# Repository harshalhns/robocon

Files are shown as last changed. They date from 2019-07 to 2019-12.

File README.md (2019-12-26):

# robocon
<pre>This project contains hardware details and AVR code for manual robot that was used in Robocon 2019. 
It is based on swerve drive. Four Atmega32 controllers are responsible for turning of each wheel to a precise target angle. 
These 4 slave controllers receive commands from master Atmega2560 via SPI. 
The robot is operated using Android mobile phone. It connects to phone through ESP8266 wifi module.</pre>

Movement of MR1: https://drive.google.com/file/d/1RZcdZKO_QcPA8YeLSfsehZz7-IaqJbko/view?ts=5e0452a6<br/>
Passing mech: https://drive.google.com/file/d/1aKHcwnHMSf9a8_czkzGeTRfraIhykFKB/view?ts=5e0452bf<br/>
Throwing mech: https://drive.google.com/file/d/1u2j3kQulj4zu3Mqgoj5k-V91Kau0ibW5/view?ts=5e045611<br/>
Movement of MR2: https://drive.google.com/file/d/1vg7AJLM3L7O4et1_eYZHAmFJQMHMDMgw/view?ts=5e045298<br/>

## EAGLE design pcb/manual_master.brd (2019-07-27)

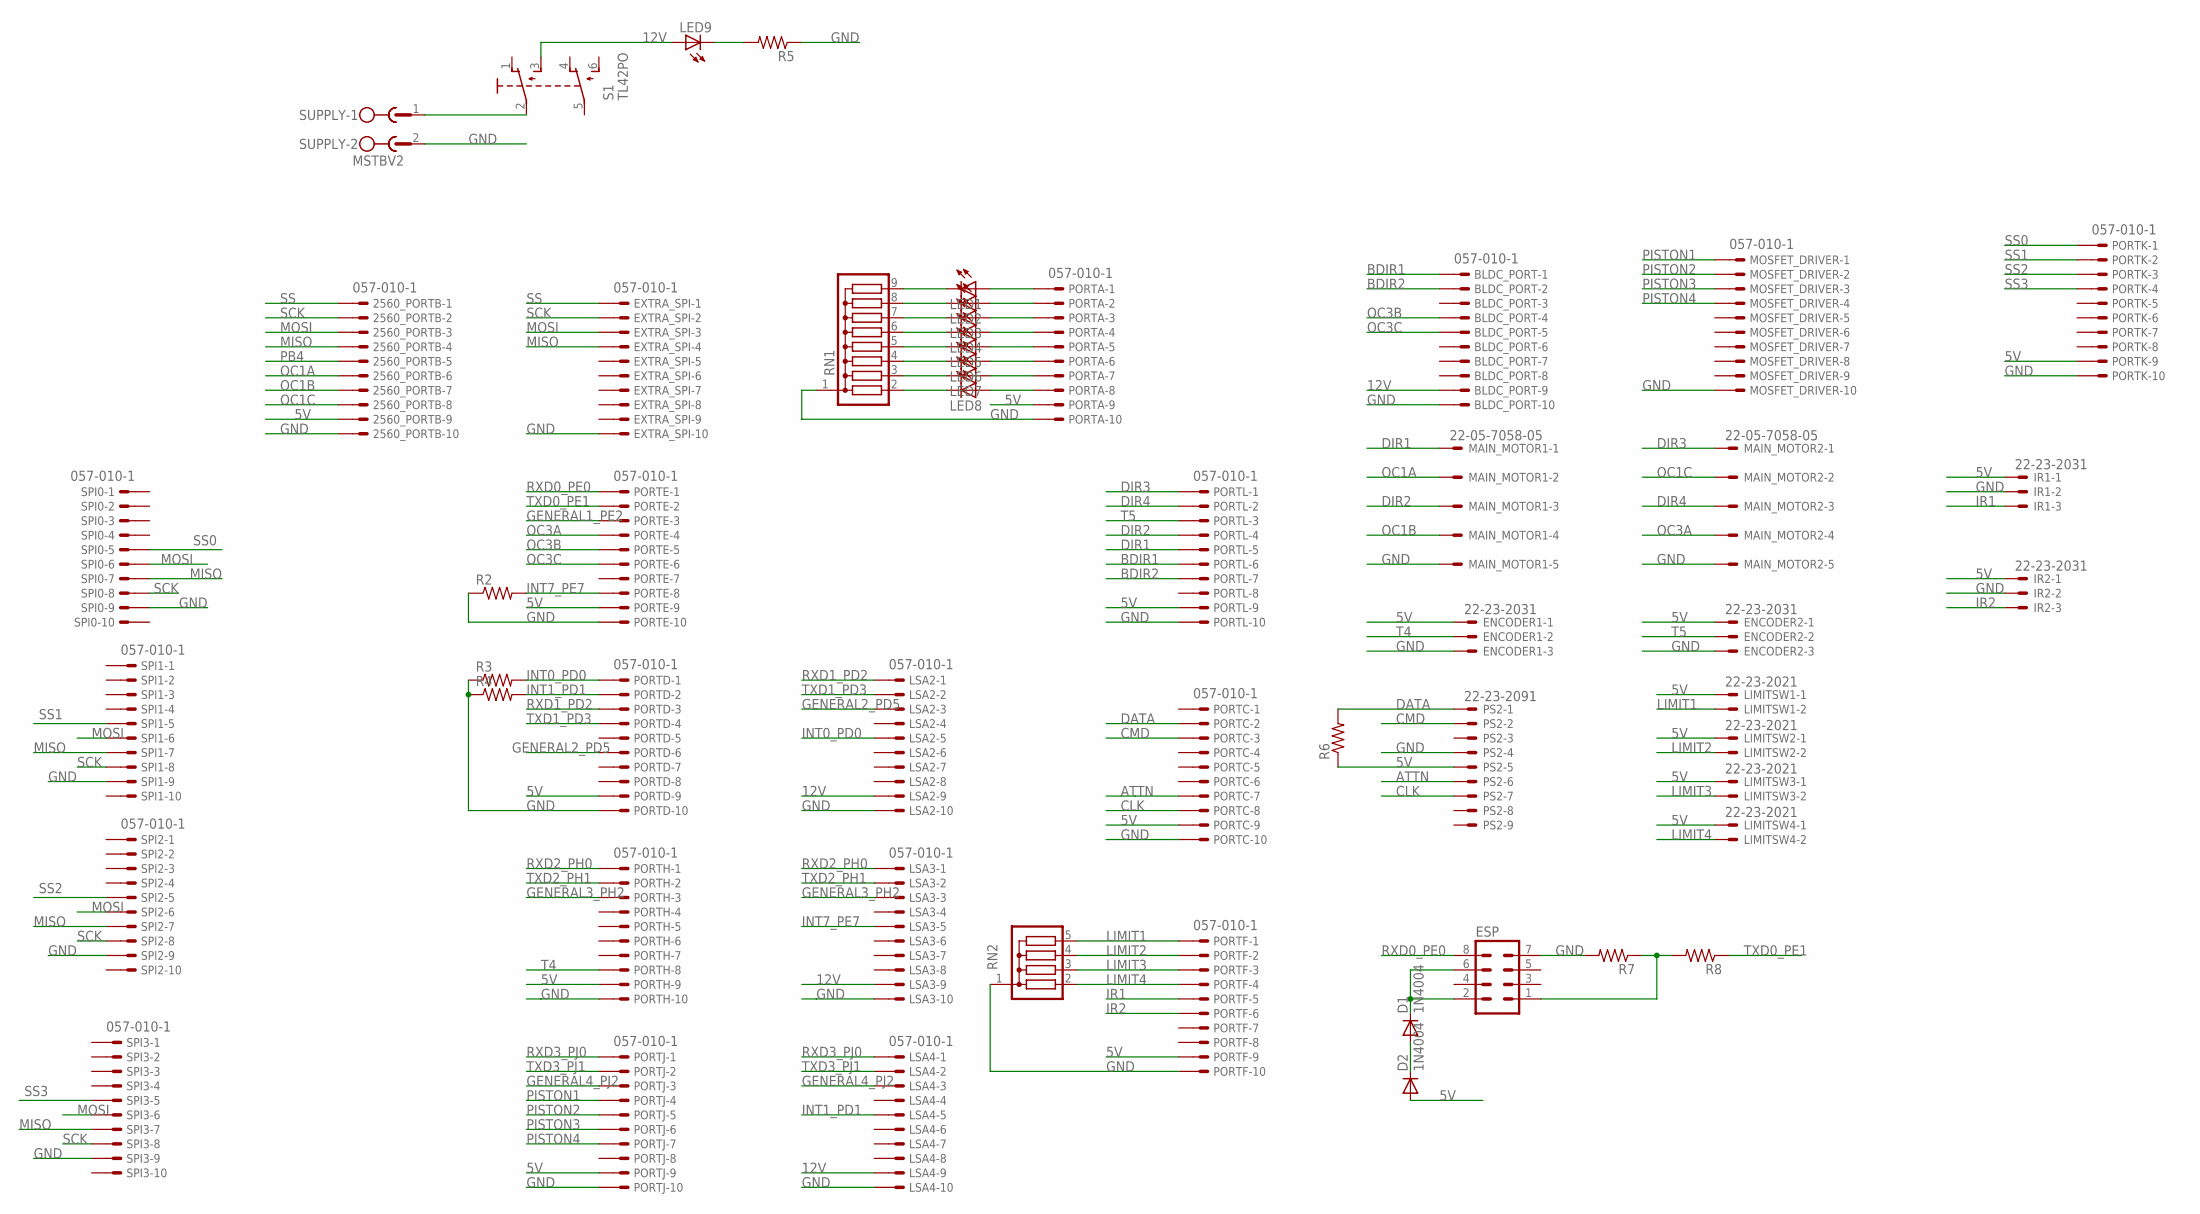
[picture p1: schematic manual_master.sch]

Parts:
2560_PORTB: 057-010-1
BLDC_PORT: 057-010-1
D1, D2: 1N4004; DO41-10
ENCODER1, ENCODER2: 22-23-2031
ESP: MA04-2
EXTRA_SPI: 057-010-1
IR1, IR2: 22-23-2031
LED1, LED2, LED3, LED4, LED5, LED6, LED7, LED8: LED3MM
LED9: LED5MM
LIMITSW1, LIMITSW2, LIMITSW3, LIMITSW4: 22-23-2021
LSA2, LSA3, LSA4: 057-010-1
MAIN_MOTOR1, MAIN_MOTOR2: 22-05-7058-05; 7395-05
MOSFET_DRIVER: 057-010-1
PORTA: 057-010-1
PORTC: 057-010-1
PORTD: 057-010-1
PORTE: 057-010-1
PORTF: 057-010-1
PORTH: 057-010-1
PORTJ: 057-010-1
PORTK: 057-010-1
PORTL: 057-010-1
PS2: 22-23-2091
R2, R3, R4, R5, R6, R7, R8: R-US_0207/10; 0207/10
RN1: G08R; SIL9
RN2: G04R; SIL5
S1: TL42PO; TL4XPO
SPI0, SPI1, SPI2, SPI3: 057-010-1
SUPPLY: MSTBV2

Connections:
5V: 2560_PORTB.9, D2.A, ENCODER1.1, ENCODER2.1, IR1.1, IR2.1, LIMITSW1.1, LIMITSW2.1, LIMITSW3.1, LIMITSW4.1, PORTA.9, PORTC.9, PORTD.9, PORTE.9, PORTF.9, PORTH.9, PORTJ.9, PORTK.9, PORTL.9, PS2.5, R6.1
12V: BLDC_PORT.9, LED9.A, LSA2.9, LSA3.9, LSA4.9, S1.3 (S)
ATTN: PORTC.7, PS2.6
BDIR1: BLDC_PORT.1, PORTL.6
BDIR2: BLDC_PORT.2, PORTL.7
CLK: PORTC.8, PS2.7
CMD: PORTC.3, PS2.2
DATA: PORTC.2, PS2.1, R6.2
DIR1: MAIN_MOTOR1.1, PORTL.5
DIR2: MAIN_MOTOR1.3, PORTL.4
DIR3: MAIN_MOTOR2.1, PORTL.1
DIR4: MAIN_MOTOR2.3, PORTL.2
GENERAL1_PE2: PORTE.3
GENERAL2_PD5: LSA2.3, PORTD.6
GENERAL3_PH2: LSA3.3, PORTH.3
GENERAL4_PJ2: LSA4.3, PORTJ.3
GND: 2560_PORTB.10, BLDC_PORT.10, ENCODER1.3, ENCODER2.3, ESP.7, EXTRA_SPI.10, IR1.2, IR2.2, LSA2.10, LSA3.10, LSA4.10, MAIN_MOTOR1.5, MAIN_MOTOR2.5, MOSFET_DRIVER.10, PORTA.10, PORTC.10, PORTD.10, PORTE.10, PORTF.10, PORTH.10, PORTJ.10, PORTK.10, PORTL.10, PS2.4, R2.1, R3.1, R4.1, R5.1, R7.2, RN1.1, RN2.1, SPI0.9, SPI1.9, SPI2.9, SPI3.9, SUPPLY.2
INT0_PD0: LSA2.5, PORTD.1, R3.2
INT1_PD1: LSA4.5, PORTD.2, R4.2
INT7_PE7: LSA3.5, PORTE.8, R2.2
IR1: IR1.3, PORTF.5
IR2: IR2.3, PORTF.6
LIMIT1: LIMITSW1.2, PORTF.1, RN2.5
LIMIT2: LIMITSW2.2, PORTF.2, RN2.4
LIMIT3: LIMITSW3.2, PORTF.3, RN2.3
LIMIT4: LIMITSW4.2, PORTF.4, RN2.2
MISO: 2560_PORTB.4, EXTRA_SPI.4, SPI0.7, SPI1.7, SPI2.7, SPI3.7
MOSI: 2560_PORTB.3, EXTRA_SPI.3, SPI0.6, SPI1.6, SPI2.6, SPI3.6
unnamed: D1.A, D2.C
unnamed: D1.C, ESP.2, ESP.6
unnamed: S1.2, SUPPLY.1
unnamed: LED9.K (C), R5.2
unnamed: LED1.A, PORTA.1
unnamed: LED2.A, PORTA.2
unnamed: LED3.A, PORTA.3
unnamed: LED4.A, PORTA.4
unnamed: LED5.A, PORTA.5
unnamed: LED6.A, PORTA.6
unnamed: LED7.A, PORTA.7
unnamed: LED8.A, PORTA.8
unnamed: LED1.K (C), RN1.9
unnamed: LED2.K (C), RN1.8
unnamed: ESP.1, R7.1, R8.2
unnamed: LED3.K (C), RN1.7
unnamed: LED4.K (C), RN1.6
unnamed: LED5.K (C), RN1.5
unnamed: LED6.K (C), RN1.4
unnamed: LED7.K (C), RN1.3
unnamed: LED8.K (C), RN1.2
OC1A: 2560_PORTB.6, MAIN_MOTOR1.2
OC1B: 2560_PORTB.7, MAIN_MOTOR1.4
OC1C: 2560_PORTB.8, MAIN_MOTOR2.2
OC3A: MAIN_MOTOR2.4, PORTE.4
OC3B: BLDC_PORT.4, PORTE.5
OC3C: BLDC_PORT.5, PORTE.6
PB4: 2560_PORTB.5
PISTON1: MOSFET_DRIVER.1, PORTJ.4
PISTON2: MOSFET_DRIVER.2, PORTJ.5
PISTON3: MOSFET_DRIVER.3, PORTJ.6
PISTON4: MOSFET_DRIVER.4, PORTJ.7
RXD0_PE0: ESP.8, PORTE.1
RXD1_PD2: LSA2.1, PORTD.3
RXD2_PH0: LSA3.1, PORTH.1
RXD3_PJ0: LSA4.1, PORTJ.1
SCK: 2560_PORTB.2, EXTRA_SPI.2, SPI0.8, SPI1.8, SPI2.8, SPI3.8
SS: 2560_PORTB.1, EXTRA_SPI.1
SS0: PORTK.1, SPI0.5
SS1: PORTK.2, SPI1.5
SS2: PORTK.3, SPI2.5
SS3: PORTK.4, SPI3.5
T4: ENCODER1.2, PORTH.8
T5: ENCODER2.2, PORTL.3
TXD0_PE1: PORTE.2, R8.1
TXD1_PD3: LSA2.2, PORTD.4
TXD2_PH1: LSA3.2, PORTH.2
TXD3_PJ1: LSA4.2, PORTJ.2

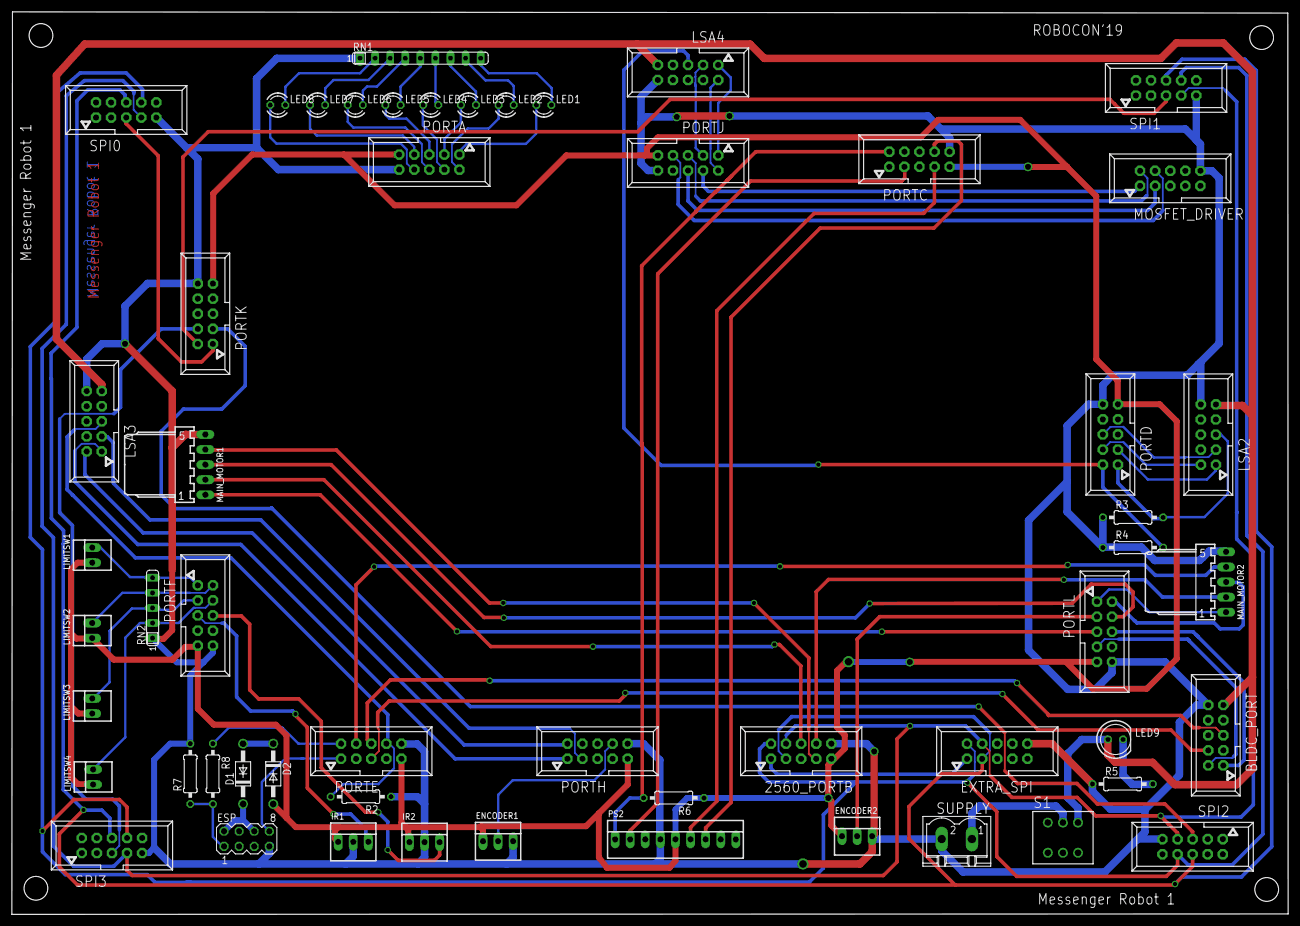
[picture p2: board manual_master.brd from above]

Board: 2 copper layers, 214.9 x 152.0 mm, 54 parts (0 on the bottom side), 74 nets.

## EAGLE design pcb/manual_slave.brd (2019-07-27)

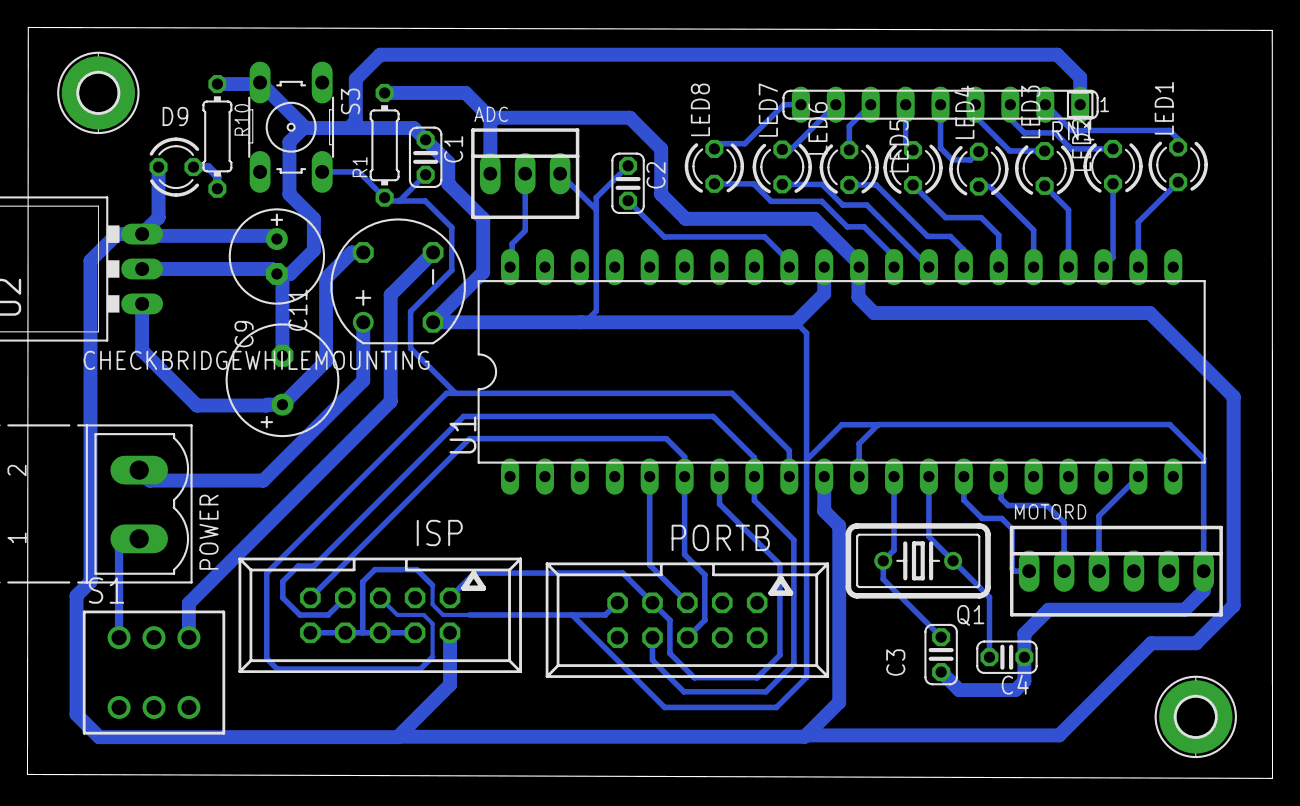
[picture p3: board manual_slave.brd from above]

Board: 2 copper layers, 90.6 x 54.6 mm, 31 parts (0 on the bottom side), 35 nets.

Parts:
ADC: 22-23-2031
C1, C2: 0.1 uf; C025-024X044
C3, C4: 22uf; C025-024X044
C9: 470uf; E3,5-8
C11: 100uf; E2,5-7
CHECKBRIDGEWHILEMOUNTING: RB1A
D9: LED3MM
H3, H4: MOUNT-PAD-ROUND2.8; 2,8-PAD
ISP: 057-010-1
LED1, LED2, LED3, LED4, LED5, LED6, LED7, LED8: LED3MM
MOTORD: 22-23-2061
PORTB: 057-010-1
POWER: MSTBV2
Q1: HC18U-V
R1, R10: 0204/7
RN1: SIL9
S1: TL42PO; TL4XPO
S3: B3F-10XX
U1: ATmega 32; DIL40
U2: 7805; 78XXL

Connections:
ADC0: ADC.2, U1.40
GND: ADC.3, C1.1, C2.1, C3.1, C4.1, C9.-, C11.-, CHECKBRIDGEWHILEMOUNTING.AC2, ISP.4, ISP.6, ISP.8, ISP.10, MOTORD.6, PORTB.9, R10.1, RN1.1, S3.3, U1.11, U1.31, U2.GND
INT0: MOTORD.1, U1.14
INT1: MOTORD.2, U1.15
unnamed: CHECKBRIDGEWHILEMOUNTING.-, S1.3
unnamed: C3.2, Q1.2, U1.12
unnamed: C4.2, Q1.1, U1.13
unnamed: C2.2, U1.32
unnamed: D9.K, R10.2
unnamed: CHECKBRIDGEWHILEMOUNTING.+, POWER.2
unnamed: LED1.K, RN1.2
unnamed: LED2.K, RN1.3
unnamed: LED3.K, RN1.4
unnamed: LED4.K, RN1.5
unnamed: LED5.K, RN1.6
unnamed: LED6.K, RN1.7
unnamed: LED7.K, RN1.8
unnamed: LED8.K, RN1.9
unnamed: POWER.1, S1.1
unnamed: C9.+, CHECKBRIDGEWHILEMOUNTING.AC1, U2.IN
PB4: PORTB.5, U1.5
PB5: ISP.9, PORTB.6, U1.6
PB6: ISP.1, PORTB.7, U1.7
PB7: ISP.7, PORTB.8, U1.8
PC0: LED1.A, U1.22
PC1: LED2.A, U1.23
PC2: LED3.A, U1.24
PC3: LED4.A, U1.25
PC4: LED5.A, U1.26
PC5: LED6.A, U1.27
PC6: LED7.A, U1.28
PC7: LED8.A, U1.29
PWM: MOTORD.3, U1.19
RESET: C1.2, ISP.5, R1.1, S3.2, U1.9
VCC: ADC.1, C11.+, D9.A, ISP.2, R1.2, U1.10, U1.30, U2.OUT

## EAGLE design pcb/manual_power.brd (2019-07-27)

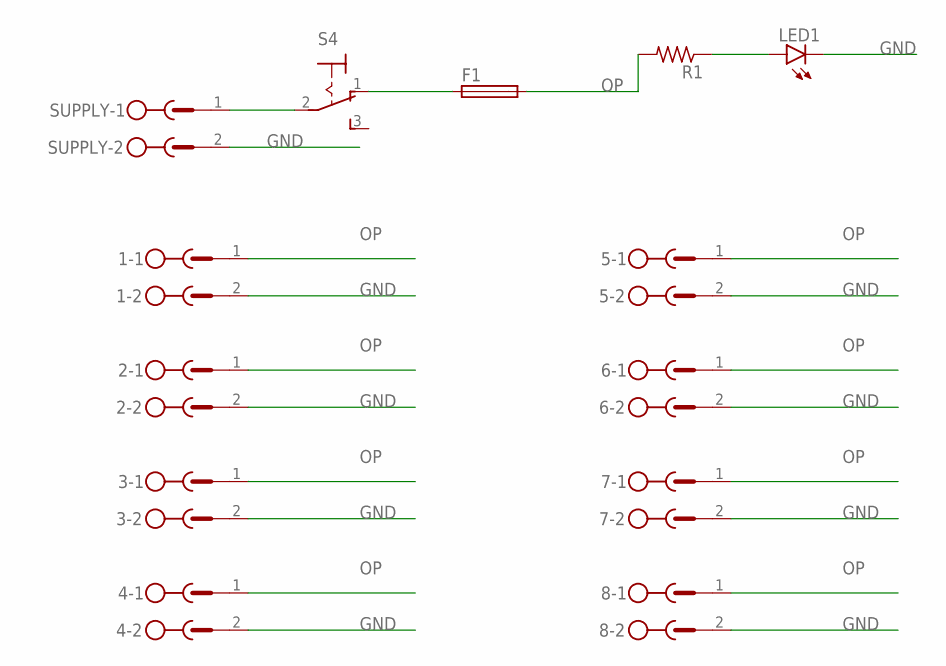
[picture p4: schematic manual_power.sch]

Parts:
1, 2, 3, 4, 5, 6, 7, 8: MSTBV2
F1: SH22
LED1: LED5MM
R1: R-US_0207/10; 0207/10
S4: 320-916
SUPPLY: MSTBV2

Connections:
GND: 1.2, 2.2, 3.2, 4.2, 5.2, 6.2, 7.2, 8.2, LED1.K (C), SUPPLY.2
unnamed: S4.2, SUPPLY.1
unnamed: LED1.A, R1.1
unnamed: F1.1, S4.1 (O)
OP: 1.1, 2.1, 3.1, 4.1, 5.1, 6.1, 7.1, 8.1, F1.2, R1.2

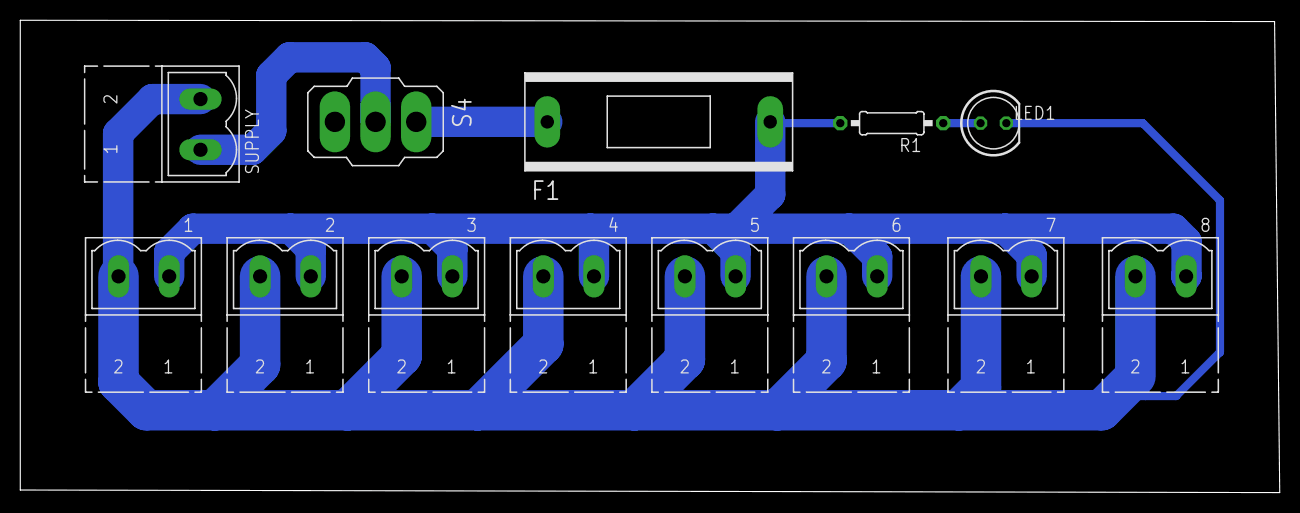
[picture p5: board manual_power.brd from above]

Board: 2 copper layers, 124.3 x 46.6 mm, 13 parts (0 on the bottom side), 5 nets.

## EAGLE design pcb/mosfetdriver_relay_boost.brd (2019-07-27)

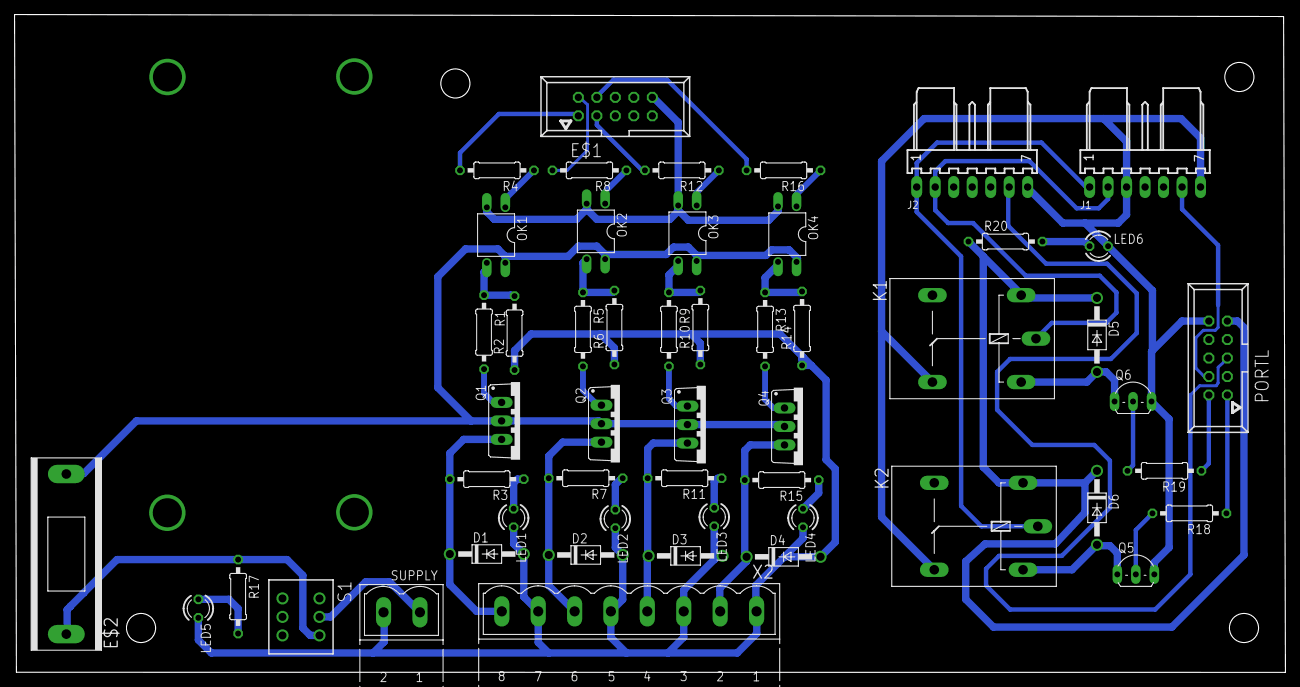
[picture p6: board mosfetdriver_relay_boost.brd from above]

Board: 2 copper layers, 174.6 x 90.4 mm, 52 parts (0 on the bottom side), 38 nets.

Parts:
D1, D2, D3, D4, D5, D6: 1N4004; DO41-10
E$1: 057-010-1
E$2: SH22
J1, J2: 22-05-7078-07; 7395-07
K1, K2: G5L; G5LE
LED1, LED2, LED3, LED4, LED5, LED6: LED3MM
OK1, OK2, OK3, OK4: PC817; DIL04
PORTL: 057-010-1
Q1, Q2, Q3, Q4: IRF540; TO220BV
Q5, Q6: BC548; TO92-EBC
R1, R5, R9, R13: 100; 0207/10
R2, R6, R10, R14: 10k; 0207/10
R3, R7, R11, R15: 1k; 0207/10
R4, R8, R12, R16: 220; 0207/10
R17, R18, R19, R20: 0207/10
S1: TL46PO; TL4XPO
SUPPLY: MSTBV2
X2: MSTBV8

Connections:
12V: D5.C, D6.C, K1.1, K2.1, PORTL.9, R20.1
+12V: OK1.4, OK2.4, OK3.4, OK4.4, Q1.D, Q2.D, Q3.D, Q4.D, R17.1, S1.3
BRK: J1.1, J2.1, K2.P
EN: J1.2, J2.2, K1.P
GND: D1.A, D2.A, D3.A, D4.A, LED1.K, LED2.K, LED3.K, LED4.K, LED5.K, R2.1, R6.1, R10.1, R14.1, SUPPLY.2, X2.1, X2.3, X2.5, X2.7
GND1: OK1.2, OK2.2, OK3.2, OK4.2
GND2: J1.3, J1.7, J2.7, K1.O, K2.O, LED6.K, PORTL.10, Q5.E, Q6.E
unnamed: OK3.1, R12.1
unnamed: OK1.3, R1.1, R2.2
unnamed: Q1.G, R1.2
unnamed: LED1.A, R3.1
unnamed: OK4.1, R16.1
unnamed: OK2.3, R5.1, R6.2
unnamed: Q2.G, R5.2
unnamed: Q6.B, R19.2
unnamed: LED2.A, R7.1
unnamed: OK2.1, R8.1
unnamed: OK3.3, R9.1, R10.2
unnamed: Q3.G, R9.2
unnamed: Q5.B, R18.2
unnamed: LED3.A, R11.1
unnamed: OK1.1, R4.1
unnamed: OK4.3, R13.1, R14.2
unnamed: Q4.G, R13.2
unnamed: D5.A, K1.2, Q6.C
unnamed: LED4.A, R15.1
unnamed: S1.2, SUPPLY.1
unnamed: D6.A, K2.2, Q5.C
unnamed: LED5.A, R17.2
unnamed: LED6.A, R20.2
OP1: D1.C, Q1.S, R3.2, X2.8
OP2: D2.C, Q2.S, R7.2, X2.6
OP3: D3.C, Q3.S, R11.2, X2.4
OP4: D4.C, Q4.S, R15.2, X2.2
P0: PORTL.1, R18.1
P1: PORTL.2, R19.1
PWM1: J1.6, PORTL.4
PWM3: J2.6, PORTL.5
